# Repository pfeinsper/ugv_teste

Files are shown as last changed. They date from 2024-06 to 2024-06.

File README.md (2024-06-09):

# Umnaned Ground Vehicle 

| Rover com suportes e câmera | Giro em torno do próprio eixo |
|---|---|
|  |   |

## Introdução
As soluções mais difundidas para o monitoramento de talhões abrangem atualmente o uso de drones, que possuem autonomia de voo limitada bem como baixa capacidade de carga. A partir desse ponto de vista, soluções terrestre se mostram vantajosas.

Este repositório comtempla os principais tópicos desenvolvidos durante o Projeto Final de Engenharia. Nele estão subdividas as adaptações e contribuições feitas ao projeto base da [Nasa](https://github.com/nasa-jpl/open-source-rover).

## Objetivos
O objetivo do projeto foi a construção de um UGV funcional, radiocontrolado, utilizando ROS2, inspirado no JPL Open Source Rover Project, com adaptações para monitoramento de talhões em citricultura, pomicultura e silvicultura.

## Requisitos 
Para o monitoramento dos talhões, câmeras de profundidade, utlizando o espectro infravermelho e visível serão usados em trabalhos futuros, além de um Lidar para auxílio no SLAM (Simultaneous localization and mapping).
Dessa forma, suportes para fixação de quatro câmeras nas laterias e um Lidar central foram desenvolvidos.

## Desenvolvimento
O projeto foi subdivido entre os integrantes do grupo para o desenvolvimento em conjunto dos tópicos de [Eletrônica](https://github.com/pfeinsper/unmaned-ground-vehicle-2024.1/tree/main/Eletr%C3%B4nica), [Mecânica](https://github.com/pfeinsper/unmaned-ground-vehicle-2024.1/tree/main/Mec%C3%A2nica) e [Software](https://github.com/pfeinsper/unmaned-ground-vehicle-2024.1/tree/main/Software).

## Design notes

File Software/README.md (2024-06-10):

# Software do UGV para Monitoramento de Talhões em Fruticultura e Silvicultura

## Visão Geral

Este projeto visa desenvolver um Veículo Terrestre Não Tripulado (UGV) para monitoramento de talhões em fruticultura e silvicultura, inspirado no projeto Open Source Rover da NASA. A seguir, detalhamos a configuração do software utilizado no UGV e os resultados obtidos com o sistema.

## Preparação do Ambiente de Desenvolvimento

### Instalação do Sistema Operacional

1. **Baixar a Imagem do Ubuntu Server**:
   - Acesse o [site oficial do Ubuntu Server](https://ubuntu.com/download/server) e baixe a imagem mais recente.
   - Utilize um software como o Raspberry Pi Imager para gravar a imagem no cartão SD.

2. **Configuração Inicial**:
   - Insira o cartão SD na Raspberry Pi e ligue o dispositivo.
   - Configure a rede Wi-Fi e outras preferências básicas durante a inicialização.
   - Atualize o sistema operacional:
     ```sh
     sudo apt update
     sudo apt upgrade
     ```

### Configuração da Raspberry Pi como Servidor e Comunicação SSH

1. **Modo Servidor**:
   - A configuração do servidor permite que a Raspberry Pi seja acessada remotamente.
   - Conecte-se ao servidor utilizando SSH:
     ```sh
     ssh embrapa@10.42.0.1
     ```

## Funcionamento do Controle

O controle remoto do UGV utiliza um transmissor de rádio controle Spektrum DXS, que comunica com um receptor instalado no UGV. O mapeamento dos botões e alavancas do controle foi configurado para facilitar a operação do UGV, permitindo controle de velocidade, direção, rotação e acionamento de funções específicas. Para configurar o controle remoto, mapeamos eixos e botões utilizando o nó `joy` do ROS 2.

### Parâmetros do Controle

- **scale_linear.x**: 0.12
- **axis_linear.x**: 1
- **axis_angular.yaw**: 2
- **axis_angular.pitch**: 4
- **scale_angular.yaw**: 1.25
- **scale_angular.pitch**: 0.25
- **scale_angular_turbo.yaw**: 0.0
- **scale_linear_turbo.x**: 0.0
- **enable_button**: 0
- **enable_turbo_button**: 1

### Rotina de Emergência

Foi implementada uma rotina de emergência para garantir a segurança operacional do rover. Ao acionar o botão de emergência, o valor de `scale_linear_turbo` é ajustado para 0.0, resultando na parada completa do rover. Foi feito um fluxograma mostrando essa rotina.

_Fluxograma de funcionamento do UGV_

Fluxograma de emergencia

# Mapeamento dos Botões e Alavancas

1. Velocidade:

   A alavanca esquerda controla a velocidade do UGV. Movendo a alavanca para frente, o UGV avança; movendo-a para trás, o UGV recua. Esta configuração é intuitiva 
   e permite um controle preciso da velocidade.

2. Direção:

   A alavanca direita é responsável pela direção do UGV. Movendo a alavanca para a esquerda ou direita, o UGV gira na respectiva direção. Este controle é 
   essencial para navegação em terrenos variados.

3. Liga/Desliga:

   O botão central inferior permite ligar ou desligar o UGV. Esta função é crucial para iniciar ou interromper a operação do UGV rapidamente.

4. Emergência:

   O botão de emergência, localizado na parte superior esquerda do controle, pode ser acionado para parar imediatamente o UGV. Este botão é mapeado para ajustar o    valor de scale_linear_turbo para 0.0, resultando na parada completa do veículo em situações de emergência.

5. Rotação:

   A rotação do UGV é controlada por um interruptor na parte superior direita do controle. Esta funcionalidade é utilizada para ajustes finos de rotação,       
   permitindo manobras precisas.

6. Deadman:

   O botão Deadman, localizado na parte traseira do controle, deve ser pressionado continuamente para manter o UGV operando. Soltar este botão resulta na parada 
   imediata do UGV, como uma medida de segurança adicional.

# Operação
Para operar o UGV, o usuário deve:

1. Ligar o Controle e o UGV:

   Pressione o botão de liga/desliga no controle e, em seguida, ligue o UGV.

2. Ajustar a Velocidade e Direção:

   Utilize as alavancas para controlar a velocidade e direção do UGV conforme necessário para a missão.

3. Monitorar a Operação:

   Esteja atento à resposta do UGV e ajuste os controles conforme necessário. Use a alavanca de rotação e o botão de emergência para manobras e paradas rápidas.

4. Segurança:

   Mantenha sempre um dedo no botão Deadman para garantir a operação segura. Em caso de emergência, utilize o botão de emergência para parar o UGV imediatamente.

# Foto do controle

Controle frente

Controle atrás

### Passos para Instalação

1. **Atualização do Sistema:**
   - `sudo apt update`
   - `sudo apt upgrade`

2. **Instalação do ROS 2 Humble:**
   - Seguir as instruções oficiais para instalação do ROS 2 Humble.

### Bringup Manual do Rover

Para iniciar manualmente o rover, execute os seguintes comandos no terminal:

1. Certificar que o programa já não esteja sendo executado:
   ```bash
   sudo systemctl stop osr_startup
   ```

2. Executar o comando de bringup:
   ```bash
   ros2 launch osr_bringup osr_launch.py
   ```

### Bringup Automático com Script de Lançamento

Para automatizar o bringup e eliminar a necessidade de acesso via SSH, configuramos a Raspberry Pi para iniciar o código do rover automaticamente.

1. Navegar até a pasta `init_scripts`:
   ```bash
   cd ~/osr_ws/src/osr-rover-code/init_scripts
   ```

2. Criar links simbólicos:
   ```bash
   sudo ln -s $(pwd)/launch_osr.sh /usr/local/bin/launch_osr.sh
   sudo ln -s $(pwd)/osr_paths.sh /usr/local/bin/osr_paths.sh
   ```

3. Copiar o arquivo de serviço para o diretório de serviços do systemd:
   ```bash
   sudo cp osr_startup.service /etc/systemd/system/osr_startup.service
   ```

4. Ajustar as permissões do arquivo de serviço:
   ```bash
   sudo chmod 644 /etc/systemd/system/osr_startup.service
   ```

### Tabela de Comandos do Bringup Automático

| Comando | Descrição |
|---|---|
| `sudo systemctl start osr_startup` | Inicia o serviço manualmente |
| `sudo systemctl stop osr_startup`  | Para o serviço manualmente |
| `sudo systemctl enable osr_startup`| Habilita o serviço no boot |
| `sudo systemctl disable osr_startup`| Desabilita o serviço no boot |
| `sudo systemctl status osr_startup`| Verifica o status do serviço |

### Configuração display LCD 16x02 com Módulo de Conversão I²C

É necessário alimentá-lo com 5V em um dos pinos de alimentação disponíveis e assinalados pelo silkscreen da brain board, bem como conectar os pinos SDA e SCL.

Ligações do display  

Após conectá-lo à placa, acessou-se o servidor via SSH e instalou-se a biblioteca `RPi_GPIO_i2c_LCD` pelo terminal:

```bash
sudo pip3 install RPi-GPIO-I2C-LCD
```

Com a biblioteca instalada, foi necessário buscar o endereço, (0x27), i2c do display usando o comando:
```bash
ubuntu@embrapa:~$ i2cdetect -y 1
```
A estratégia adotada para redução de consumo foi atualizar o display em um determinado tempo, para isso foi necessário adicionar via editor ‘nano’ um comando para executar o script a cada 5 minutos:
```bash
ubuntu@embrapa:~$ crontab -e
```

Na última linha adicionou-se o código:
```bash
*/5 * * * * /usr/bin/python3 /home/ubuntu/osr_ws/src/ihm_lcd.py
```

### Aquisição de Imagens

1. **Instalação de Bibliotecas Necessárias**:
   ```sh
   sudo apt install ros-humble-cv-bridge
   sudo apt install ros-humble-image-transport
   ```

2. **Configuração de Câmeras**:
   - Conecte as câmeras Intel RealSense D435i e Logitech C920 HD PRO na Raspberry Pi.
   - Utilize os seguintes comandos para verificar e ajustar as configurações:
     ```sh
     rs-enumerate-devices
     v4l2-ctl --list-devices
     ```

3. **Publicação e Visualização de Imagens**:
   - Execute os nós ROS para capturar e publicar imagens:
     ```sh
     ros2 run realsense2_camera realsense2_camera_node
     ros2 run image_transport republish raw in:=/camera/color/image_raw out:=/image_raw
     ```
   - Outra forma de inicializar a captação de imagens consiste em rodar o codigo abaixo:
     ```sh
     systemctl restart start_turtle.service
     ```
   - Para visualizar as imagens usar Rviz2 ou rqt_image_view:
   - rqt_image_view:
     ```sh
     ros2 run rqt_image_view rqt_image_view
     ```
   - Rviz2:
     ```sh
     Rviz2
     ```

### Instalação do ROS Humble

1. **Adicionar Chave do Repositório ROS**:
   ```sh
   sudo apt install software-properties-common
   sudo add-apt-repository universe
   sudo apt update
   sudo apt install curl
   curl -sSL https://raw.githubusercontent.com/ros/rosdistro/master/ros.asc | sudo apt-key add -
   ```

2. **Adicionar Repositório ROS**:
   ```sh
   sudo sh -c 'echo "deb http://packages.ros.org/ros2/ubuntu $(lsb_release -cs) main" > /etc/apt/sources.list.d/ros2-latest.list'
   sudo apt update
   sudo apt install ros-humble-desktop
   ```

3. **Configurar Ambiente ROS**:
   Adicione as seguintes linhas ao arquivo `~/.bashrc`:
   ```sh
   source /opt/ros/humble/setup.bash
   ```

## Resultados

### Visualização e Monitoramento

1. **Interface Gráfica (Rviz2)**:
   - Utilizada para visualização dos tópicos ROS, incluindo as imagens capturadas pelas câmeras.
   - Permite monitorar a posição e o status dos sensores em tempo real.

2. **Aquisição de Imagens**:
   - As câmeras Intel RealSense D435i capturam imagens com profundidade, permitindo a criação de mapas 3D do ambiente.
   - As imagens são publicadas em tópicos ROS e podem ser visualizadas remotamente.

### Desempenho e Processamento

1. **Processamento em Tempo Real**:
   - A configuração em modo servidor da Raspberry Pi, aliada ao ROS, permite o processamento eficiente das imagens capturadas.
   - O sistema foi capaz de lidar com o processamento de múltiplos streams de imagem simultaneamente sem atraso significativo.

2. **Estabilidade e Confiabilidade**:
   - O sistema demonstrou estabilidade durante os testes, com a comunicação SSH permitindo controle remoto seguro e eficaz.
   - A integração com o ROS possibilitou a fácil adição e modificação de nós conforme necessário, garantindo flexibilidade para futuras expansões.

## Contribuidores

- Breno Alencar Araújo
- Bruno Morales Balkins
- Fernando Bichuette Assumpção
- Giulia Carolina Martins de Sampaio

Orientador: Prof. Dr. Vinícius Licks
Mentor: Thiago Teixeira Santos

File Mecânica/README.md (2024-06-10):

# Mecânica

## Modelo 3D
O modelo base 3D pode ser encontrado em [OnShape](https://cad.onshape.com/documents/e4f00b1a3d2edb1a84bbba1c/w/8ab8f394324bcc586236ef5d/e/9191e5ad2a70f387b419bc55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) ou no arquivo STEP fornecido acima.



## Adaptações da Documentação Oficial
Foram necessárias algumas adaptações na montagem da documentação oficial, uma vez que os componentes eram importados e parte deles não estava disponível para entrega. Para contornar esse problema, foram compradas peças equivalentes que permitissem adaptação para a aplicação proposta.
A seguir, as peças que passaram por esse processo adaptativo estão listadas e comentadas.
### Perfis da Suspensão
As primeiras peças a serem adaptadas foram os perfis de alumínio que compõem parte da suspensão do robô, uma vez que não foi possível encontrá-los nos comprimentos especificados na documentação oficial da Nasa, de 96mm. Como alternativa foram comprados perfis de tamanho superior, que foram cortados na dimensão correta.



Após o corte dos perfis, a rosca para alocação do parafuso M4 utilizado na montagem precisou ser refeita para todos os quatro furos de cada uma das peças cortadas. A operação de rosqueamento foi realizada manualmente e composta por três etapas, utilizando machos de tamanhos diferentes até chegar no tamanho desejado da rosca. A peça não precisou ser furada novamente, uma vez que seus furos eram passantes, abrangendo toda a estrutura, independente do comprimento.



### Barras de Alumínio do Corpo 
As barras de alumínio utilizadas na montagem do corpo do robô também precisaram ser adaptadas, uma vez que também foram compradas em comprimento superior ao especificado e depois cortadas no tamanho correto, de 96 mm.

Após realização das operações de corte nas peças, foi necessário realizar a furação das barras, uma vez que o furo existente não era passante como no perfil. Além disso, também foi necessário realizar o rosqueamento em duas etapas, bem como ocorreu com a outra peça citada anteriormente.

Na operação de furação foram realizadas as seguintes etapas para garantir um melhor alinhamento do furo:
1.	pintura da face a ser furada com um marcador.
2.	Remoção da tinta para marcação do furo com auxílio de um marcador de altura vertical. Traçado realizado com dimensão equivalente à metade do lado da face, garantindo que as retas se cruzem no centro.
3.	Realização de uma marcação central para garantir que a broca não seja inserida de forma desalinhada, etapa realizada com um equipamento de punção de centro, uma morsa e um martelo.
4.	Furação com auxílio de uma fresadora manual de bancada, buscando alinhar a ponta da broca com a marcação realizada na etapa anterior. Avançar e recuar a broca durante o processo, garantindo escoamento do cavaco e dissipação do calor gerado.



O processo de rosqueamento também foi necessário e foi refeito de forma identica ao procedimento descrito para os perfis. 

A peça com o rolamento para encaixe da suspensão também não estava disponível no modelo original da documentação da NASA, dessa forma foi adotada outra com diâmetro interno equivalente (Figura 28). Embora a substituta não encaixe perfeitamente e cause uma leve deformação estrutural, optou-se por não realizar nenhuma adaptação pois os componentes poderiam ser danificados e não possuíam substitutos. O efeito de deformação resultante não comprometeu o funcionamento do rover. 



## Revisão de Erros da Documentação Oficial 

Um dos componentes da suspensão foi identificado erroneamente na documentação oficial, com código inicial 1601, que na realidade corresponde ao componente número 1611. Na visualização 3D da montagem, a peça identificada com código correspondente ao informado na documentação oficial apresenta diâmetro interno com valor inferior a 8mm, não montando no eixo especificado.



## Componentes Adicionais Fabricados

Para garantir a adaptabilidade do robô ao ambiente de monitoramento, alguns componentes adicionais precisaram ser fabricados, dentre eles os suporte das câmeras e o do LiDAR, permitindo que esses componentes sejam futuramente alocados na estrutura.

### Suporte das Câmeras

Como requisitado pelo cliente, também foram desenvolvidos alguns suportes para câmeras e um LIDAR, utilizando o software Fusion 360 para modelagem e a tecnologia de impressão 3D para materialização do projeto.

suporte1

Screenshot at Jun 10 11-16-50

### Suporte do LiDAR

suporte3

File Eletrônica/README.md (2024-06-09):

# Eletrônica

## Esquemáticos e Detalhamento Geral de Funcionamento

A eletrônica do protótipo é composta por duas placas: a placa de acionamento dos motores (Motor Board), onde estão localizados os circuitos de potência e a placa responsável por comandar todo o funcionamento do sistema (Brain Board), onde estão circuitos de controle e está alocada uma Raspberry Pi 4, modelo B de 8 GB, com microprocessador quad-core de 64-bits ARM-Cortex A72, rodando a 1,5 GHz.



### Diagramas de Alimentação 

Analisando primeiro a alimentação do sistema, uma bateria fornecendo 14,8V DC é conectada diretamente à placa de acionamento, passando por um circuito de proteção, que possui um fusível, um resistor de 1 kΩ e um diodo, que atuam como proteção do circuito dos motores. Além disso, um módulo de monitoramento de tensão e corrente (INA260) é utilizado para medição de sobrecorrente, além de um multímetro, que é utilizado para monitoramento do usuário dos dados de corrente e tensão.



A tensão 14,8V é usada na alimentação de dois reguladores, um step-down de 12V (D24V22Fx), usado para alimentar os drivers da Roboclaw e outro de 5V (D24V150Fx). Há também um terceiro regulador de tensão que converte a tensão de 5V para 3,3V (MIC2937A-3.3WT), alimentando o módulo de expansão de PWM (PCA9685), o monitor de tensão e corrente e os LED’s de sinalização de ambas as placas. A tensão de 5V, por sua vez, também realiza a alimentação do módulo de expansão de PWM, dos servos, da Raspberry Pi, do display da IHM e dos encoders dos motores. Os motores são alimentados pela Roboclaw via PWM com tensão máxima de 12V.

### Diagramas de Sinais

Para o diagrama de sinais do sistema, note que um novo bloco foi adicionado, o conjunto entre o operador e o rádio controle, responsável por enviar os comandos por meio de ondas de rádio até a Raspberry Pi, que recebe o sinal por meio de um módulo USB. Os dados recebidos pelo microprocessador são enviados na serial e usados para o controle dos motores e servos. 



A malha de controle dos seis motores é comandada pela Raspberry Pi, que recebe a referência do rádio controle e envia os comandos para os drivers da Roboclaw, que realizam o acionamento via PWM. O fechamento da malha é realizado pelos encoders, que são responsáveis pelo sensoriamento, enviando os dados coletados ao controlador presente no driver.

Os quatro servos, por sua vez, são controlados em malha aberta (fechada internamente) acionados por meio de um sinal PWM. Este sinal é fornecido pelo módulo PCA9685 (expansão), usado para ampliar a quantidade de servos que podem ser controlados, por meio da geração de 16 novos canais PWM. A comunicação desse módulo com a Raspberry Pi ocorre por meio do protocolo de comunicação I2C.

Considerando a comunicação do micro-computador com o módulo de monitoramento de tensão e corrente (INA260), nota-se que o envio de dados também ocorre por meio de um protocolo de comunicação I2C. O módulo também se comunica com os LED’s de sinalização para alertar o usuário caso seu resistor de shunt interno detecte alguma alteração no sistema de alimentação.

Além do módulo de expansão e do monitor, a comunicação com o display da IHM, que será futuramente implementada, também ocorrerá de acordo com o protocolo I2C. O motivo para tal escolha é que a placa de controle apresenta um barramento I2C disponível, que poderia ser adaptado para a conexão do display com baixa quantidade de adaptações necessárias.

Outra observação importante em relação ao diagrama é que a Raspberry Pi também está responsável pelo controle do regulador de tensão de 12V por meio de um sinal de enable, ligando ou desligando o output de 12V.

Analisando um pouco mais a placa de controle, observa-se a presença de alguns LED’s de sinalização, esses componentes possuem como finalidade a comunicação com o usuário, sinalizando por exemplo quando ocorre a transferência de dados pela serial, acendendo quando os bits são transferidos. 

Por fim, o último fluxo de dados a ser analisado é o indicador do estado de emergência, no qual um sinal digital de nível lógico alto é enviado pelo botão de emergência ao microprocessador, que comunica a situação ao usuário por meio do display da IHM. 

## Circuito de Emergência Físico

O esquemático do circuito de emergência físico utilizado para desernegizar o robô está ilustrado a seguir.



Para indicação do estado de emergência ao usuário, foi adotado um sinaleiro vermelho, que acende assim que o botão for pressionado. O componente apresenta uma resistência interna de 1800 Ω, suportando tensões de até 24V e seu acionamento é realizado por uma chave normalmente aberta, responsável por fechar o circuito após pressionamento do botão. 

Foi implementado também um botão de emergência remoto, cujo funcionamento está explicado na pasta de programação. 

## Detalhamento Circuito Display

O esquemático de conexão de pinos do display para garantir a comunicação I2C está representado a seguir. Os pinos para conexão de 5V e GND estão disponíveis na raspberry pi e uma extensão dos pinos SCL e SDA pode ser encontrada na placa de controle.



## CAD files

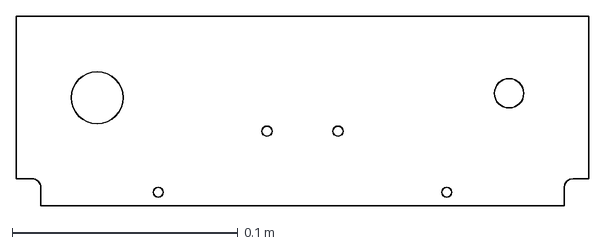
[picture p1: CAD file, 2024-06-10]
Mecânica/dxf acrilico/topo_frente.dxf
0.254 x 0.084 m

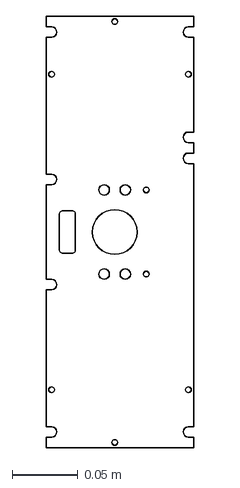
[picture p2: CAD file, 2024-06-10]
Mecânica/dxf acrilico/lado.dxf
0.112 x 0.328 m

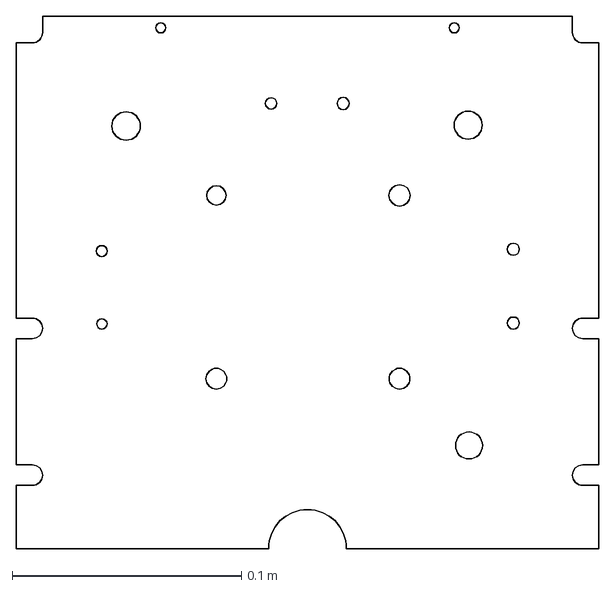
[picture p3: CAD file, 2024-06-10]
Mecânica/dxf acrilico/topo_tras.dxf
0.254 x 0.232 m

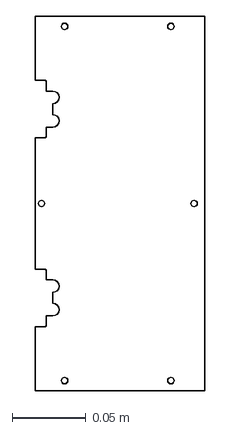
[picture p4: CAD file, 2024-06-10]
Mecânica/dxf acrilico/traseira.dxf
0.115 x 0.254 m

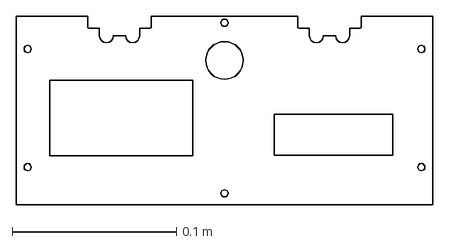
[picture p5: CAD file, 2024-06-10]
Mecânica/dxf acrilico/frente.dxf
0.254 x 0.115 m

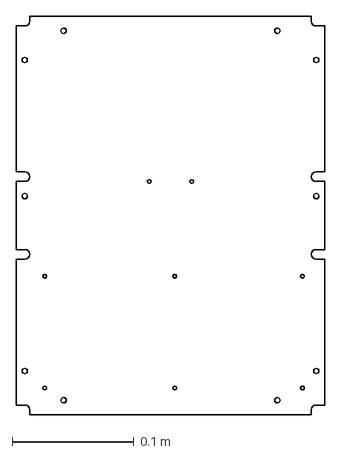
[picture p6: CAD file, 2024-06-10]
Mecânica/dxf acrilico/base.dxf
0.254 x 0.328 m

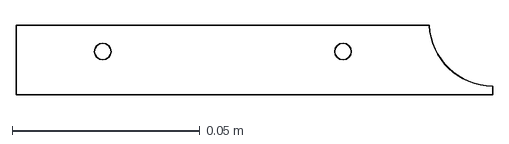
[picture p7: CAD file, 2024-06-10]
Mecânica/dxf acrilico/buraco_superior.dxf
0.127 x 0.0185 m

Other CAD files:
Mecânica/Modelagem 3D acrilico/base.f3d
Mecânica/Modelagem 3D acrilico/buraco_superior.f3d
Mecânica/Modelagem 3D acrilico/frente.f3d
Mecânica/Modelagem 3D acrilico/lado.f3d
Mecânica/Modelagem 3D acrilico/topo_frente.f3d
Mecânica/Modelagem 3D acrilico/topo_tras.f3d
Mecânica/Modelagem 3D acrilico/traseira.f3d
Mecânica/Modelagem 3D suportes/suporte_camera_base.f3d
Mecânica/Modelagem 3D suportes/suporte_camera_fixador.f3d
Mecânica/Modelagem 3D suportes/suporte_lidar.f3d

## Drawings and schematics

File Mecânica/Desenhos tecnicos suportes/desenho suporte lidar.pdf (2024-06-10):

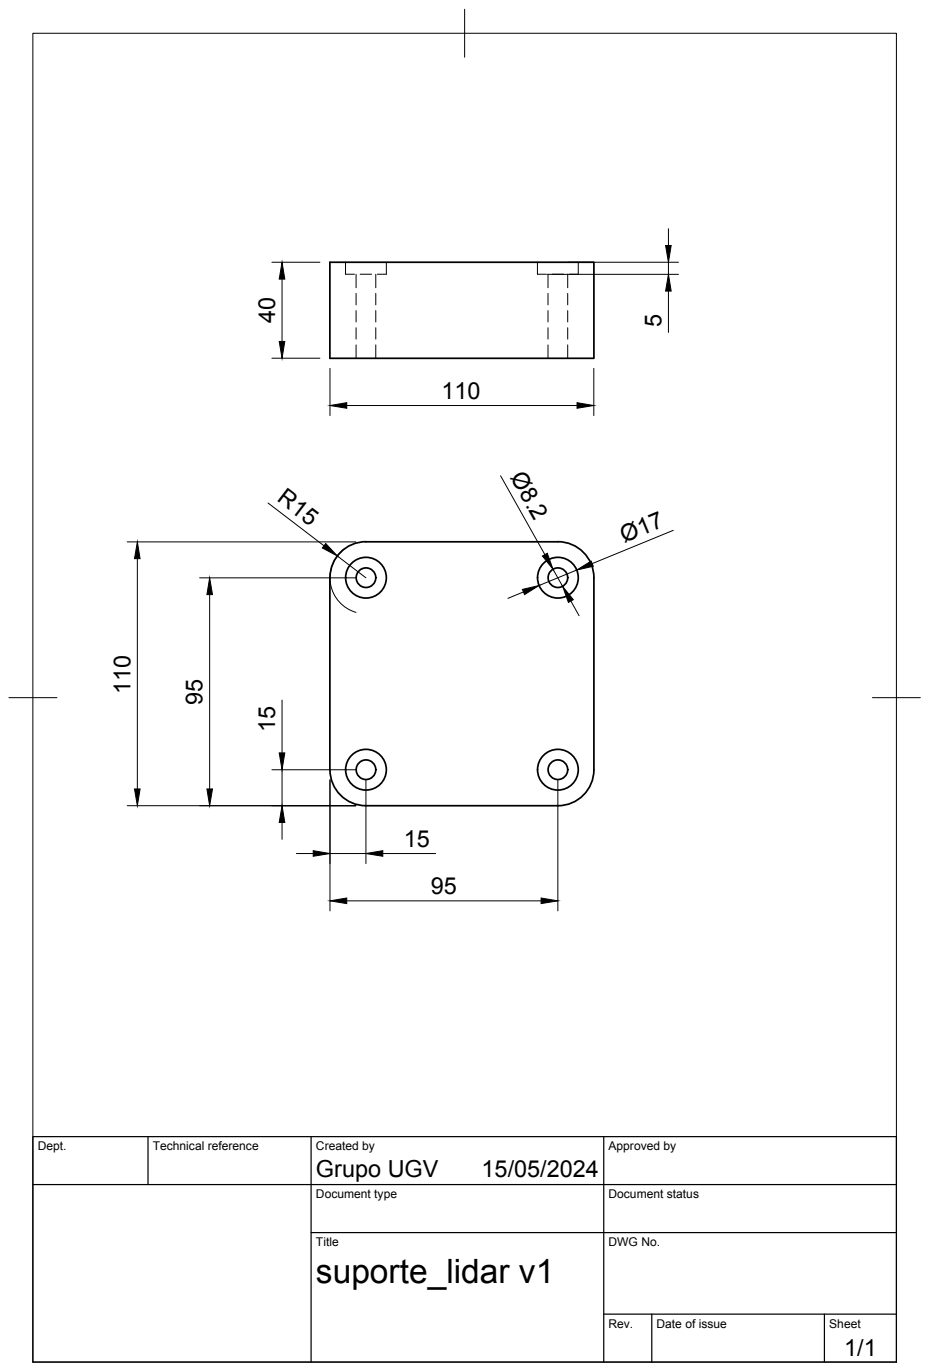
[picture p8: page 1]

Dept. | Technical reference | Created by Grupo UGV 15/05/2024 | Approved by

Document type | Document status

Title suporte_lidar v1 | DWG No.

Rev. | Date of issue | Sheet 1/1

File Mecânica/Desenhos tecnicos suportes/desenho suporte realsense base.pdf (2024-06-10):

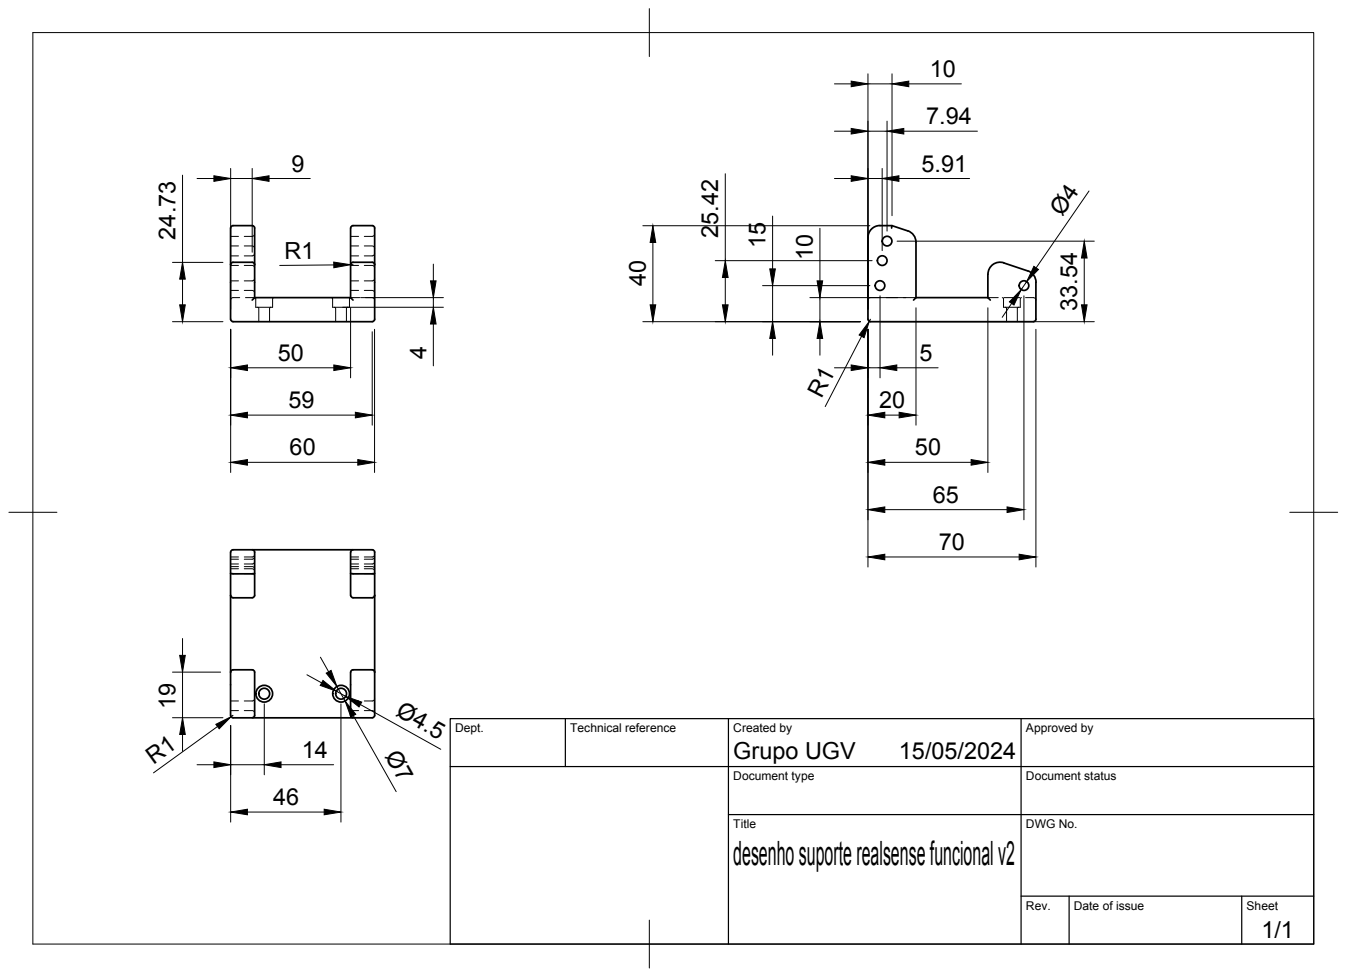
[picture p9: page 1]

Dept. | Technical reference | Created by Grupo UGV 15/05/2024 | Approved by

Document type | Document status

Title desenho suporte realsense funcional v2 | DWG No.

Rev. | Date of issue | Sheet 1/1

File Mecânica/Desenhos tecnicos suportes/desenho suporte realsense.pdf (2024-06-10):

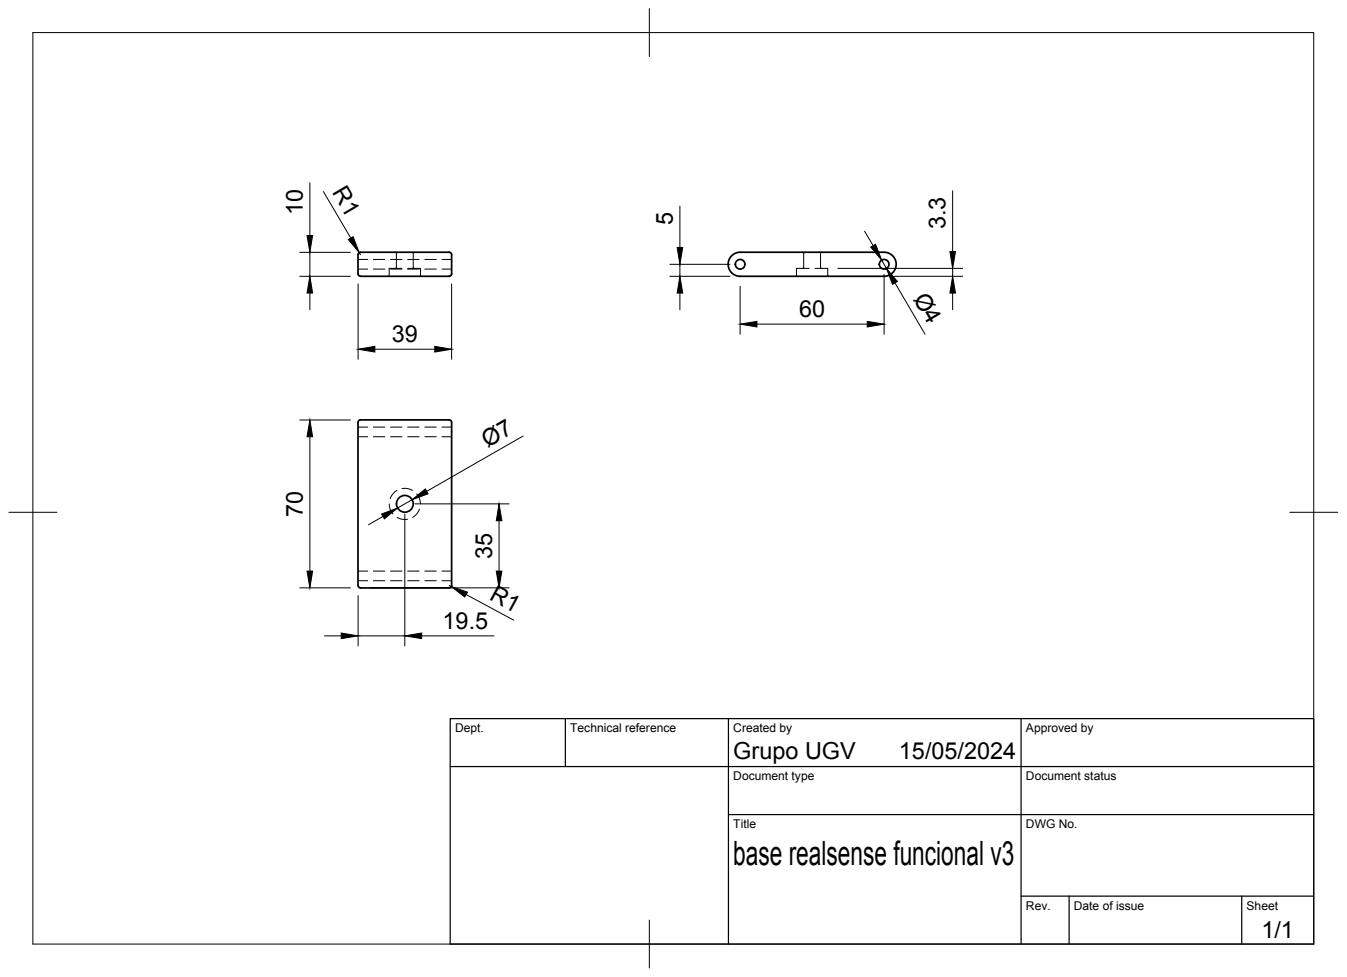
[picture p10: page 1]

Dept. | Technical reference | Created by Grupo UGV 15/05/2024 | Approved by

Document type | Document status

Title base realsense funcional v3 | DWG No.

Rev. | Date of issue | Sheet 1/1

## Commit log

2024-06-09 Update README.md
    adição de imagens
2024-06-09 Update README.md
    ajuste de imagens
2024-06-09 Update README.md
    links para as pastas
2024-06-09 Update README.md
    remoçao de comentários
